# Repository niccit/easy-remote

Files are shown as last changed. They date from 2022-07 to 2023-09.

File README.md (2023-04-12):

# Easy Remote with LED Display

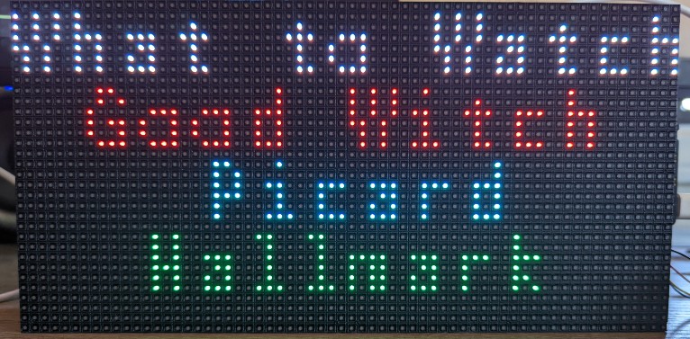
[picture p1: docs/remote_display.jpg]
Picture of LED display


## The Need
As my mom gets older, she is having trouble working the remote for her Roku devices.

I searched for a senior-friendly remote that worked with Roku but was unable to find one that didn't have way too many tiny buttons on it.

## The Solution
Build a 4-button remote with a large display.

Color code the buttons, LED lights on the keyboard, and text on the display.
- Red: Netflix
- Blue: Paramount/Pluto TV
- Green: Hallmark
- White: Power

This project is tailored to her watching habits, however, it can be easily modified.

In addition to the keypad this implementation will:
- Interact with the TV streaming Netflix every hour to avoid the "Are you still watching message"
- Turn primary and secondary TVs on and off automatically

## How it works
The project is coded in <a href="https://circuitpython.org/" target="_blank">CircuitPython</a>

You will notice that there are four launch_service methods, although only three can be used if you leave the fourth button for power. I added the launch_pluto method late and just swapped it out with the launch_paramount method. Hopefully, this shows how flexible you can be with this project.

You will need to create your own secrets file based on the example file included in the project. Documentation for building a secrets file can be found <a href="https://learn.adafruit.com/electronic-history-of-the-day-with-pyportal/code-walkthrough-secrets-py" target="_blank">here.</a>

To better understand how to interact with the Roku devices, please visit the <a href="`https://developer.roku.com/en-ca/docs/developer-program/debugging/external-control-api.md`" target="_blank">Roku Developers : External Control Protocol (ECP) documentation.</a>

Adafruit libraries this project needs:
- adafruit_bitmap_font
- adafruit_bus_device
- adafruit_display_text
- adafruit_esp32spi
- adafruit_io
- adafruit_neokey
- adafruit_matrixportal
- adafruit_requests.mpy

All configurable data is stored in the data file:
- device_hosts : One or more Roku devices available on the network
- service_port : The service port for the Roku device
- shows : The shows the person using this remote likes to watch
- channels :  The Roku channel names
- channel_numbers : The corresponding Roku channel IDs - see the ECP for how to get a channel ID
- frndly_guide_position : Unfortunately, Frndly TV app currently doesn't support the Roku search controls. For now you have to find your channel in the guide and count how many down from the top it is and us it for this value.
- netflix_search_int : Netflix doesn't put you back to the starting position on the search grid, so you have to note how many moves right it is from the last letter in your search to the program you want to select.
- paramount_search_int : Paramount moves where they leave the search cursor, use this value to change how many times to move the cursor in order to select the desired show
- primary_tv_start_time : The time, stored in an array [h, m], you want the primary television to turn on each day
- primary_tv_end_time : The time, stored in an array [h, m], you want the primary television to turn off each day
- secondary_tv_start_time: The time, stored in an array [h, m], you want the secondary television to turn on each day
- secondary_tv_end_time: The time, stored in an array [h, m], you want the secondary television to turn off each day
- update_delay : This is the first of the main while loops. General setup/housekeeping, doesn't need to run often. Set to 1 hour
- interact_delay: This is the second of the main while loops, it interacts with Netflix and handles automatic start/stop of the devices. Set to 20 miutes
- remote_reboot_time: The time, stored in an array [h, m], you want the remote to reboot each day

### Why I chose to use a data file?
I wanted the code to be flexible with as little hard coding as possible. It's much easier to edit the data file then to make changes directly in the code.

## The hardware
All the hardware is from <a href="https://www.adafruit.com" target="_blank">Adafruit.</a>

- <a href="https://www.adafruit.com/product/4812" target="_blank">Adafruit Matrix Portal Starter Kit - ADABOX 016 Essentials</a>
  - You can also get all the parts separately:
    - <a href="https://www.adafruit.com/product/4745" target="_blank">Adafruit Matrix Portal</a>
    - <a href="https://www.adafruit.com/product/2278" target="_blank">64 x 32 RGB Matrix</a>
    - <a href="https://www.adafruit.com/product/4749" target="_blank">LED Diffusion Acrylic</a>
    - <a href="https://www.adafruit.com/product/4813" target="_blank">Adhesive Squares</a>
    - <a href="https://www.adafruit.com/product/1995" target="_blank">5V 2.4A Power Supply</a> + <a href="https://www.adafruit.com/product/4299" target="_blank">USB C adapter</a>
- <a href="https://www.adafruit.com/product/4980" target="_blank">NeoKey 1x4 QT I2C - Four Mechanical Key Switches with NeoPixels - STEMMA QT / Qwiic</a>
    - If you want to include the volume buttons you'll need a second NeoKey keyboard
    - I've modified the OpenSCAD file for the keyboard case to support 2 or 4 keys
- <a href="https://www.adafruit.com/product/4955" target="_blank">Kailh Mechanical Key Switches - Clicky White - 10 pack - Cherry MX White Compatible</a>
- <a href="https://www.adafruit.com/product/4997" target="_blank">DSA Keycaps for MX Compatipe Switches - 10 pack</a>
	 - Colors used: Red, Dark Blue, Neon Green, White
- <a href="https://www.adafruit.com/product/4210" target="_blank">STEMMA QT/Qwiic JST SH 4-pin Cable - 100mm long</a>
	 - You can also build your own
- <a href="https://www.adafruit.com/product/4756" target="_blank">Adafruit LTC4311 `I2C Extender / Active Terminator` - STEMMA QT / Qwiic</a>
      - You need this if you want to run a long STEMMA QT cable - so the remote can sit in front of the remote, not on the side

## 3D printing
The stand is designed in OpenSCAD and the source and STL files are included in the project. For my printer I had to break the stand into two halves. In order to do this there is a mortise/tenon joint to join the halves. If your printer is big enough you can print the whole unit at once. STL files are provided for each half, the entire stand, the keyboard cover, offsets, and screws.

No matter how you print it you will need to print the offsets, screws, and keyboard cover separately.
- If you have M3 screws and offsets you can forego printing those
- if you have M4 screws you can forego printing the screws
- The LED display has M3 threaded holes
- The offsets and keyboard tray use M4 threaded holes
  - I went up to M4 because I found that size printed more reliably

I have not included supports in the STL files. You will need to add supports into your slicer or the print will not come out as intended.

The logo on the back of the stand is my 'tip of the hat' and thank you to Adafruit and the Adafruit community. Feel free to comment out the design or substitute your own.

- Printer - Flashforge Adventurer 4
- Slicing software - FlashPrint

- Filament and Slicing:
   - PLA for the stand, offset, and screws
      - Standard 1.75mm filament
      - Extruder: .4/240c
      - Extruder Temp: 210c
      - Platform Temp: 50
      - Supports:
         - Yes for the tenon joint on the left side
            - Linear
            - Manual
	 - Raft: Yes for the stand
	    - Above Raft Extrusion Ratio : 75%
	    - Space to Model (Z) : 0.18mm
   - PETG for the keyboard cover
      - Color: Transparent
      - Extruder: .4/265c
      - Extruder Temp: 240c
      - Platform Temp: 80c
      - Supports: No
      - Raft: Yes
        - Above Raft Extrusion Ratio : 75%
        - Space to Model (Z) : 0.18mm

Huge thank you to HopefulLlama and rcoyler for sharing their libraries with the OpenSCAD community!

- Joint library provided by HopefulLlama
  - <a href="https://github.com/HopefulLlama/JointSCAD" target="_blank">Github project</a>
  - <a href="https://www.thingiverse.com/groups/openscad/forums/general/topic:14842" target="_blank">Thingiverse</a>
- Threads library provided by rcoyler
  - <a href="https://github.com/rcolyer/threads-scad" target="_blank">Github project</a>

## To-Do

- Switch to a socketpool
   - I'm hoping this helps with overall stability
	- In addition it will allow the user to push a button while backround checks and maintenance tasks are happening

 ## FAQ

 - My remote is up and running, but after about 6-8 hours it stops communicating with the devices. If I look at the REPL it says my active devices are inactive.
   - You are likely running the default firmware on your Matrix Portal M4 board
	- **Solution:** Upgrade the firmware, by following these [instructions](https://learn.adafruit.com/upgrading-esp32-firmware/upgrade-all-in-one-esp32-airlift-firmware).

- The software periodically crashes with a seesaw error, when I reset I get the error message "No pull up found. check your wiring".
  - **FIRST:** Ensure you're using a [STEMMA QT/Qwiic cable](https://www.adafruit.com/product/4399)
  - Posted in the Adafruit forums about this issue. 
  - **Solution** This seems to be specific to this board, so between your Matrix Portal 4 and the Keyboard, put an Adafruit LTC4311 I2C Extender / Active Terminator - STEMMA QT / Qwiic
     - The part is linked above in the hardware section.

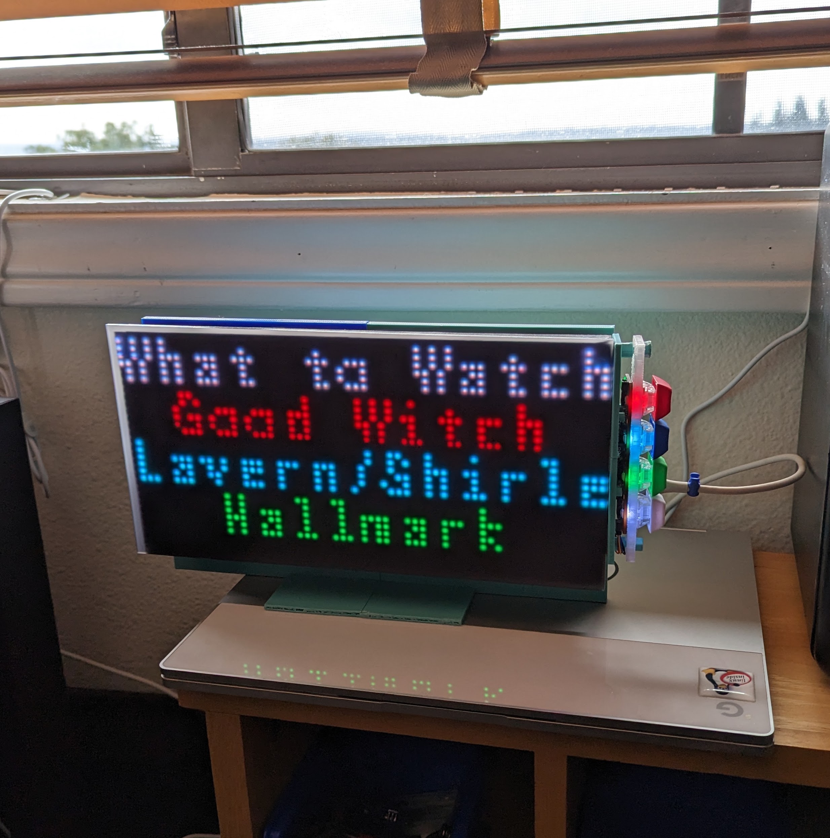
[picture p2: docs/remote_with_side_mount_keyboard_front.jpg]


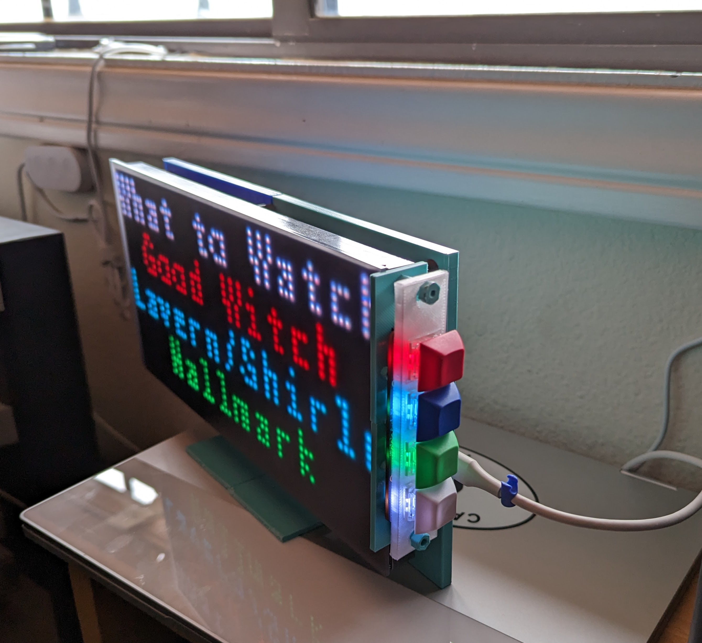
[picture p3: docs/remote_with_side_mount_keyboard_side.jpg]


- Every so often the screen is stuck on "Loading Please Wait"
   - See the To-Do list

- Every so often the remote is unresponsive when pressing a button or it takes a long time to start handling the button request
   - See the To-Do list

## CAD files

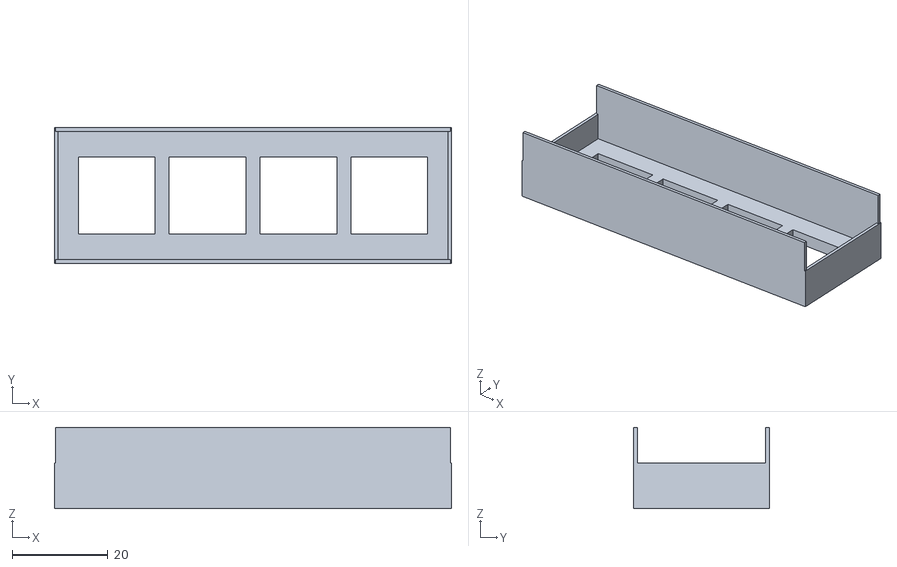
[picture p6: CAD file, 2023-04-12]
STL_files/led_keyboard_cover.stl
82.9 x 28.3 x 17.0

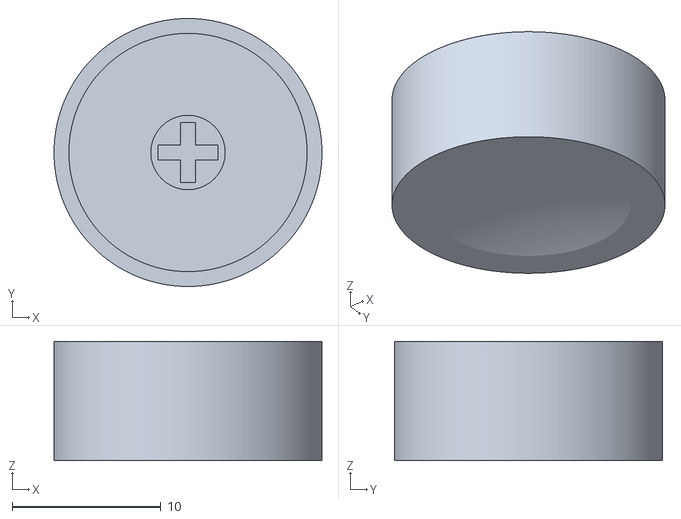
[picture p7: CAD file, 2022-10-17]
STL_files/keycap_round_blank.stl
18.0 x 18.0 x 8.00

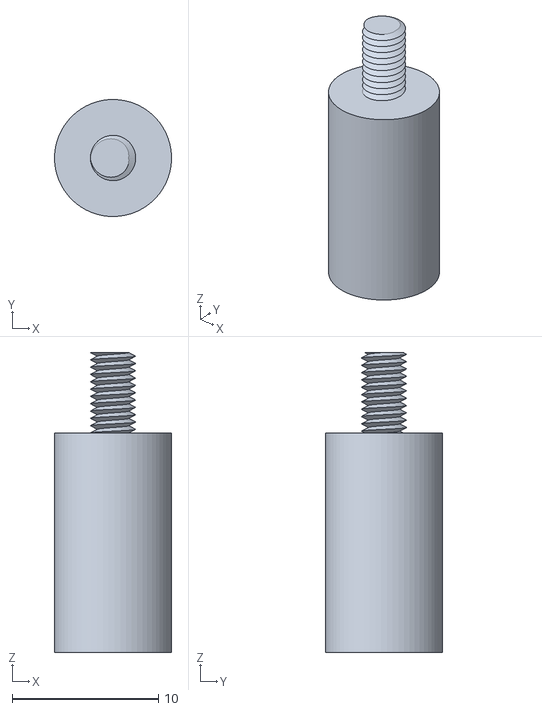
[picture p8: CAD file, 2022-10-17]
STL_files/led_stand_offset.stl
8.00 x 8.00 x 20.5

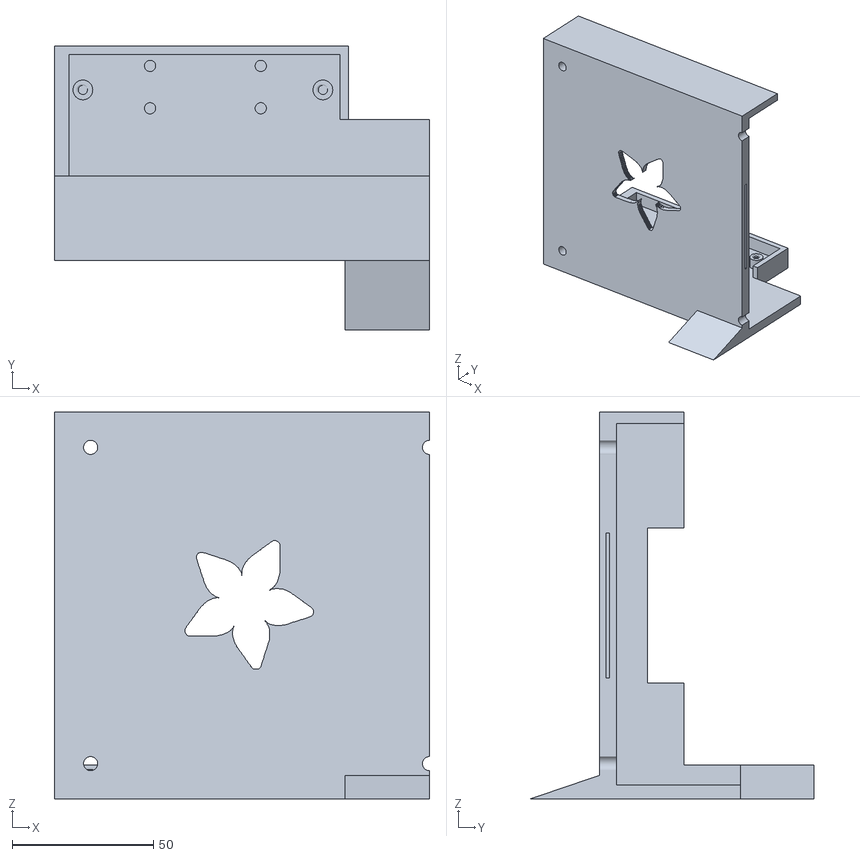
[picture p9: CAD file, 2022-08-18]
STL_files/led_stand_backplate_right.stl
132.8 x 100.5 x 137.0

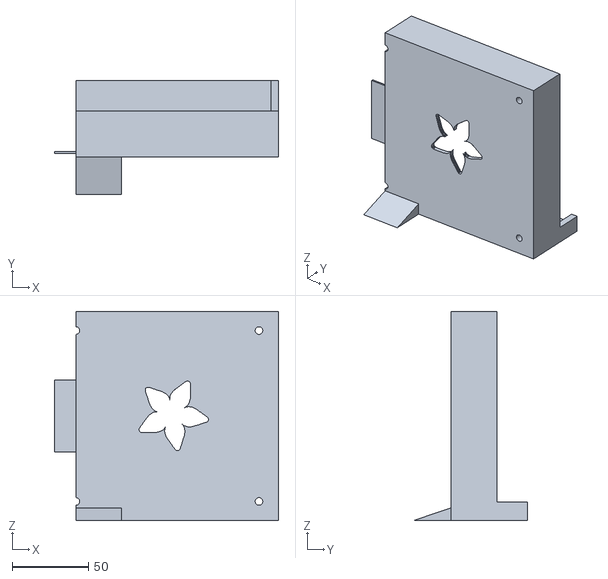
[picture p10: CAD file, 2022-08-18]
STL_files/led_stand_backplate_left.stl
146.8 x 74.5 x 137.0

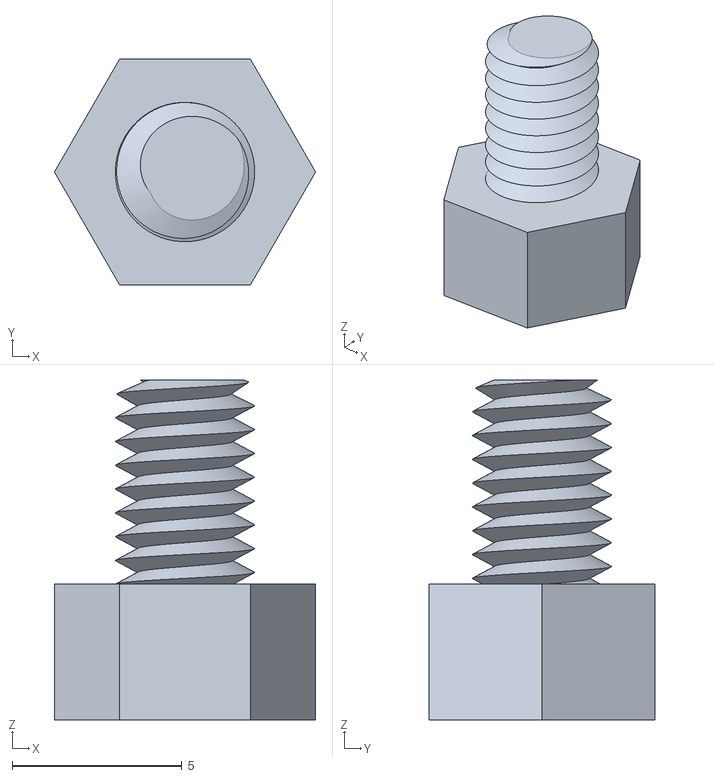
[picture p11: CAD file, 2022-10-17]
STL_files/kb_bolt.stl
7.68 x 6.65 x 10.0

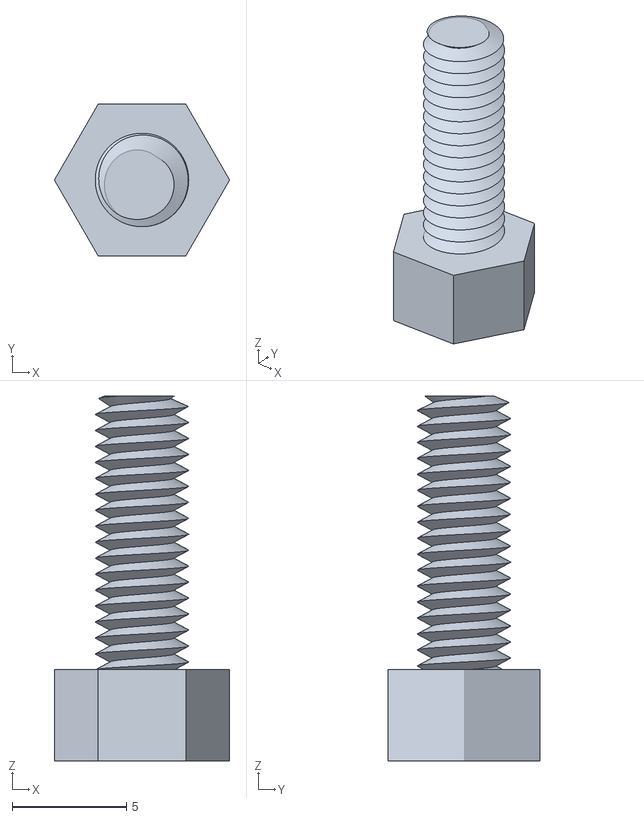
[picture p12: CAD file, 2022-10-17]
STL_files/led_bolt.stl
7.68 x 6.65 x 16.0

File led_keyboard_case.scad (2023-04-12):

// SPDX-License-Identifier: MIT
$fa = 1;
$fs = 0.4;

// keyboard tray
kb_length = 76.2;
kb_width = 21.59;
kb_height = 4;

front_length = kb_length;
front_width = 17;
front_height = 0.75;

mounting_hole_diam = 2.45;
mounting_hole_height = 4;
mounting_hole_distance = 2.51;

// ### Begin Modules ###

module base_cube() {
    difference() {
        cube([kb_length + 10, kb_width + 10, kb_height], center=true);
        translate([0, 0, kb_height])
            cube([kb_length + 8, kb_width + 8, kb_height + 1]);
    }
}

// For fitting top and bottom together
module base_hollow_outline() {
    difference() {
        cube([kb_length + 7, kb_width + 7, kb_height], center=true);
        cube([kb_length + 5, kb_width + 5, kb_height + 1], center=true);
    }
}

module base_with_snapfit() {
    difference() {
        base_cube();
        translate([0, 0, kb_height - 1.5])
            base_hollow_outline();
    }
}

module complete_base() {
    difference() {
        base_with_snapfit();
        translate([-kb_length/2 + 19.05, kb_width/2 - mounting_hole_distance, 0])
            cylinder(d=mounting_hole_diam, h=mounting_hole_height, center=true);
        translate([kb_length/2 - 19.05, kb_width/2 - mounting_hole_distance, 0])
            cylinder(d=mounting_hole_diam, h=mounting_hole_height, center=true);
        translate([-kb_length/2 + 19.05, -kb_width/2 + mounting_hole_distance, 0])
            cylinder(d=mounting_hole_diam, h=mounting_hole_height, center=true);
        translate([kb_length/2 - 19.05, -kb_width/2 + mounting_hole_distance, 0])
            cylinder(d=mounting_hole_diam, h=mounting_hole_height, center=true);
    }
}

module keyboard_cover(num, space) {
  difference() {
    cube([kb_length + 6.25, kb_width + 6, kb_height - 1], center=true);
		for (i = [0 : num - 1])
            if (num == 4) {
                translate([-kb_length / 2 + 9.6 + space*i, 0, 0])
                    children(0);
            }
            else {
                translate([-kb_length / 2 + 29 + space*i, 0, 0])
                    children(0);
            }
	}
    // front
    rotate([90,0,0])
    translate([0, -front_width / 2 + 1.5, kb_width / 2 + 3 - 0.001])
        cube([front_length + 6.25, front_width, front_height], center = true);
    // back
    rotate([90,0,0])
    translate([0, -front_width / 2 + 1.5, -kb_width / 2 - 3 - 0.001])
        cube([front_length + 6.25, front_width, front_height], center = true);
    // left side
    rotate([90, 0, 90])
    if (num == 4) {
        translate([0, -front_width / 2 + 5.25, kb_length / 2 + 3 - 0.001])
        cube([kb_width + 6.75, front_width - 7.5, front_height], center = true);
    }
    else {
        translate([0, -front_width / 2 + 1.5, kb_length / 2 + 3 - 0.001])
        cube([kb_width + 6.75, front_width, front_height], center = true);
    }
    // right side
   rotate([90, 0, 90])
   translate([0, -front_width / 2 + 5.25, -kb_length / 2 - 3 - 0.001])
        cube([kb_width + 6.75, front_width - 7.5, front_height], center = true);
}


module key_holes(){
  cube([16, 16, kb_height], center=true);
}

// ### End Modules ###

// Construction of the parts

show_base = 0;
show_top = 0;
show_all = 1;
do_rotate = 0;
keys = 4;


if (show_base == 1) {
    if (do_rotate == 1) {
        rotate([180, 0, 0])
            complete_base();
    }
    else {
        complete_base();
    }
}

if (show_top == 1) {
    if (do_rotate == 1) {
        rotate([180, 0, 0])
            keyboard_cover(keys, 19) key_holes();
    }
    else {
        keyboard_cover(keys, 19) key_holes();
    }
}

if (show_all == 1) {
    complete_base();
    rotate([180, 0, 0])
    translate([kb_length + 20, 0, 0])
        keyboard_cover(4, 19) key_holes();
}

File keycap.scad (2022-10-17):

// SPDX-License-Identifier: MIT
//
// A round keycap for Cherry MX keyboard
// Can be blank or have a raised letter added
//

$fa = 1;
$fs = 0.4;

difference() {
	// outer cylinder
	outer_cylinder();
	// inner cylinder
	translate([0, 0, 1])
		cylinder(r=8, h=7, center=true);
}

translate([0, 0, 0.25 - 0.001])
	key_lock();

//
// Show a letter on your key
// Use 0 for a blank key
//
translate([0.5, 0, 0])
	show_text(0);

//
// Modules
//

module outer_cylinder() {
	difference() {
		cylinder(r=9, h=8, center=true);
			rotate([0,180,0])
			translate([0, 0, 26])
				sphere(r=23);
	}
}

module key_lock () {
	difference() {
		cylinder(r=2.5, h=6, center=true);
		translate([0,0,1])
			cube([1, 4, 5], center=true);
		translate([0,0,1])
			cube([4, 1, 5], center=true);
	}
}

module show_text (num) {
	rotate([180,0,0])
	if (num==1)
		translate([-4.5, -3.5, 3])
			linear_extrude(height = 1)
				text("N", font = "Liberation Sans:style=Bold", size= 8);
	else if (num==2)
		translate([-4, -3.5, 3])
			linear_extrude(height = 1)
				text("P", font = "Liberation Sans:style=Bold", size=8);
	else if (num==3)
		translate([-4.5, -3.5, 3])
			linear_extrude(height = 1)
				text("H", font = "Liberation Sans:style=Bold", size=8);
	else if (num==4)
		rotate([0, 0, 180])
		translate([-5, -2.5, 3])
			linear_extrude(height = 1)
				text("Off", font = "Liberation Sans:style=Bold", size=5);
}

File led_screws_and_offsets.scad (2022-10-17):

// SPDX-License-Identifier: MIT
//
// Offsets for mounting display to stand and
// screws for securing display to offsets and keyboard cover
//

use <lib/threads.scad>

$fa = 1;
$fs = 0.4;

// Bolts & Clearance Holes
bolt_size = 4;
offset_bolt = 3;
offset_bolt_height = 6;
kb_bolt_height = 6;
base_bolt_height = 12;
base_screwHole_height = 9;

// Offsets for LED / back of stand
//
offset_with_bolt();

// Bolt for securing LED to back of stand
//
translate([0, 15, -10])
	MetricBolt(bolt_size, base_bolt_height);

// Bolt for securing keyboard cover
//
translate([0, 30, -10])
	MetricBolt(bolt_size, kb_bolt_height);





module offset_base() {
	difference() {
    cylinder(r=4, h=15, center=true);
			ScrewHole(outer_diam=bolt_size, height=base_screwHole_height);
	}
}

module offset_with_bolt() {
	translate([0, 0, 5 - 0.001])
	 ScrewThread(outer_diam=offset_bolt, height=offset_bolt_height);
	rotate([0,180,0])
	translate([0,0,2 - 0.001])
	 offset_base();
}

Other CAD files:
STL_files/keycap_round_hallmark.stl
STL_files/keycap_round_netflix.stl
STL_files/keycap_round_paramount.stl
STL_files/keycap_round_power.stl
led_stand.scad

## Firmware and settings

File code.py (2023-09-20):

# SPDX-License-Identifier: MIT
# This is a very simple remote, designed for individuals with difficulty navigating
# all the different streaming applications
# It was designed to help a senior have less frustration while trying to watch television
import ssl
import time
import board
import displayio
import re
import socketpool
import wifi
import adafruit_requests
import adafruit_ntp
import adafruit_logging as logger
from adafruit_neokey.neokey1x4 import NeoKey1x4

# Get WiFi information from secrets.py file
try:
    from secrets import secrets
except ImportError:
    print("WiFi secrets are kept in secrets.py, please add them there")
    raise

# Get data needed to launch shows and interact with devices
try:
    from data import data
except ImportError:
    print("Cannot import data file")
    raise

# Get what we need from the data file
hosts = data["device_hosts"]
port = data["service_port"]
current_shows = data["shows"]
current_channels = data["channels"]
channel_ids = data["channel_numbers"]
pluto_shows = data["pluto_shows_array"]
roku_shows = data["roku_shows_array"]
paramount_shows = data["paramount_shows_array"]
netflix_search_int = data["netflix_search_array"]
primary_tv_start_time = data["primary_tv_start_time"]
primary_tv_end_time = data["primary_tv_end_time"]
primary_tv_channel = data["primary_tv_channel"]
secondary_tv_start_time = data["secondary_tv_start_time"]
secondary_tv_end_time = data["secondary_tv_end_time"]
secondary_tv_channel = data["secondary_tv_channel"]
secondary_device = data["secondary_device_active"]
update_delay = data["update_delay"]
interact_delay = data["interact_delay"]
key_input_delay = data["key_input_delay"]
live_check = data["live_check"]
tz_offset = data["tz_offset"]
log_level = data["log_level"]

# --- Setup  ---

# Network Variables
SSID = secrets["ssid"]
WIFI_PASS = secrets["password"]

# Device Interaction Variables
INPUT_WAIT_TIME = key_input_delay
CHECK_STRING = live_check
TZ_OFFSET = float(tz_offset)
if secondary_device != 0:  # There is a second TV in the house
    SECOND_TV = True
else:  # There is only one TV
    SECOND_TV = False
CHOICE = 0
RUNNING_APP = 0
RUNNING_SHOW = None
LAST_CHECK = None
INTERACT_CHECK = None
PRIMARY_ACTIVE_APP = None
SECONDARY_ACTIVE_APP = None
PRIMARY_CHANNEL_NAME = None
SECONDARY_CHANNEL_NAME = None
PRIMARY_SHOW_NAME = None
SECONDARY_SHOW_NAME = None

# Logging
LOGGER = logger.getLogger('console')
if log_level is "debug":
    LOGGER.setLevel(logger.DEBUG)
elif log_level is "info":
    LOGGER.setLevel(logger.INFO)
elif log_level is "warning":
    LOGGER.setLevel(logger.WARNING)
elif log_level is "error":
    LOGGER.setLevel(logger.ERROR)
elif log_level is "critical":
    LOGGER.setLevel(logger.CRITICAL)
else:
    print("setting log level to critical")
    LOGGER.setLevel(logger.CRITICAL)

LOGGER.info("log level is " + log_level)

# URLs
URL_1 = ("http://" + hosts[0] + ":" + port + "/")
URL_2 = ("http://" + hosts[1] + ":" + port + "/")

# Host IPs, for ping check
HOST_1_IP = hosts[0]
HOST_2_IP = hosts[1]

# Build array of channel ID ints
CHANNEL_ID_INTS = []
for i in range(len(channel_ids)):
    CHANNEL_ID_INTS.append(int(channel_ids[i]))

# --- Network Setup --- #

# Socketpool and requests for talking to devices
pool = socketpool.SocketPool(wifi.radio)
requests = adafruit_requests.Session(pool, ssl.create_default_context())

# NTP
ntp = adafruit_ntp.NTP(pool, tz_offset=TZ_OFFSET)

# --- Neokey Setup --- #

color = displayio.Palette(7)
color[0] = 0XFF0000  # red = Show 1
color[1] = 0x008000  # green = Show 3

i2c_bus = board.STEMMA_I2C()
neokey = NeoKey1x4(i2c_bus, addr=0x30)

# Set colors for the keyboard
neokey.pixels[0] = color[1]
neokey.pixels[3] = color[0]


# --- Roku API Calls --- #
home = "keypress/home"  # Home
right = "keypress/right"  # Right
left = "keypress/left"  # Left
up = "keypress/up"  # Up
down = "keypress/down"  # Down
back = "keypress/back"  # Back
select = "keypress/select"  # Select
vol_up = "keypress/volumeup"  # Volume Up
vol_down = "keypress/volumedown"  # Volume Down
pwr_on = "keypress/poweron"  # Power On
pwr_off = "keypress/poweroff"  # Power Off
launch = "launch/"  # Launch a Channel
active_app = "query/active-app"  # Query Active Application
query_media = "query/media-player"  # Query Device State


# --- Helper methods not related to Roku devices --- #

# Get current time from NTP and return it
def get_time():
    cur_time = None

    while cur_time is None:
        try:
            cur_time = ntp.datetime
        except RuntimeError as e:
            LOGGER.error("get_time: An error occurred, retrying ... " + str(e))
            continue

    return cur_time


# Convert a show name to an array for searching
def get_show_search_array(show_to_watch):
    show_to_split = show_to_watch.split()
    show_to_split_length = len(show_to_split)
    show_array = []
    counter = 0
    for word in show_to_split:
        counter += 1
        if counter < show_to_split_length:
            show_array += list(word)
            show_array += " "
        else:
            show_array += list(word)
    return show_array


# --- Helper methods to assist in channel/show launching --- #

# Set global variables needed to interact with the devices
def set_channel_and_show(url, show_to_watch):
    global PRIMARY_CHANNEL_NAME, SECONDARY_CHANNEL_NAME, PRIMARY_SHOW_NAME, SECONDARY_SHOW_NAME, \
        PRIMARY_ACTIVE_APP, SECONDARY_ACTIVE_APP

    show_configured = False

    while show_configured is False:
        for show in range(len(current_shows)):
            if show_to_watch is current_shows[show]:
                channel_to_watch = current_channels[show]
                app_to_watch = channel_ids[show]
                if url is URL_1:
                    PRIMARY_CHANNEL_NAME = channel_to_watch
                    PRIMARY_SHOW_NAME = show_to_watch
                    PRIMARY_ACTIVE_APP = int(app_to_watch)
                else:
                    SECONDARY_CHANNEL_NAME = channel_to_watch
                    SECONDARY_SHOW_NAME = show_to_watch
                    SECONDARY_ACTIVE_APP = int(app_to_watch)
                show_configured = True


# Use in-channel search to locate show to watch
# Using search as a more reliable way to find what to watch
def search_program(url, show_to_watch):
    if url:
        device_url = url
    else:
        device_url = URL_1

    search_show = get_show_search_array(show_to_watch)
    time.sleep(1)

    for letter in search_show:
        command = ("keypress/Lit_" + letter)
        send_request(device_url, command)
        time.sleep(0.5)


# Query the devices to determine if they are online
def get_device_state(url):
    device_state = "inactive"

    if url:
        device_url = url
    else:
        device_url = URL_1

    LOGGER.debug("get_device_state: querying " + str(device_url) + " for status")
    if send_request(device_url, query_media) is not None:
        device_state = "active"

    return device_state


# Get the active app ID
def get_active_app(url):
    active_channel = 0

    if url:
        device_url = url
    else:
        device_url = URL_1

    if device_url is URL_1:
        app_state = primary_device_state
        app_id_to_check = PRIMARY_ACTIVE_APP
    else:
        app_state = secondary_device_state
        app_id_to_check = SECONDARY_ACTIVE_APP

    if app_state is "active" and app_id_to_check is None:
        LOGGER.debug("get_active_app: Attempting to get active channel for device " + str(device_url))
        channel_text = send_request(device_url, active_app)
        if channel_text is not None:
            regex = re.compile("[\r\n]")
            parsed_response = regex.split(channel_text)
            regex = re.compile("[\"]")
            tmp_channel = (regex.split(parsed_response[2]))
            active_channel = tmp_channel[1]
        else:
            LOGGER.critical("get_active_app: failed to get response from device for active channel")
    else:
        print("already have active app for URL")
        active_channel = app_id_to_check

    LOGGER.debug("active app is now set to " + str(active_channel))

    return active_channel


# Determine which item we want in a channel's watch list
# This only works as long as the show stays in the watch list after viewing it
#    and the app doesn't shift the position of the items in the watch list based
#    on what was watched most recently
def get_addtl_show_info(show_to_watch, channel):
    position = 0
    search_array = []
    if channel is "Pluto":
        search_array = pluto_shows
    if channel is "Roku":
        search_array = roku_shows
    if channel is "Paramount":
        search_array = paramount_shows
    if channel is "Netflix":
        search_array = netflix_search_int

    for show in range(len(search_array)):
        if show_to_watch in search_array[show]:
            show = search_array[show]
            position = show[1]
    return position


# Send command to appropriate Roku device
def send_request(url, command):
    result = None

    try:
        if "active-app" in command:
            LOGGER.debug("querying for active app")
            response = requests.get(url + command)
            result = response.text
            response.close()
        elif "media-player" in command:
            LOGGER.debug("querying media player")
            response = requests.get(url + command)
            result = response.text
            response.close()
        else:
            response = requests.post(url + command)
            result = "true"
            response.close()
    except Exception as e:
        LOGGER.error("send_request: Caught generic exception " + str(e) + " for command " + str(command))

    return result


# Exit current running app and power down the Roku TV or put the Roku device into sleep mode
def power_off(url):
    LOGGER.info("request to power off")
    if url:
        device_url = url
    else:
        device_url = URL_1

    if device_url is URL_1:
        app = PRIMARY_ACTIVE_APP
    else:
        app = SECONDARY_ACTIVE_APP

    # Check to see if we need to properly exit or if we can just return to home screen
    if app == 12:
        exit_netflix(device_url)
        time.sleep(1)
    elif app == 74519:
        exit_pluto(device_url)
        time.sleep(1)
    else:
        send_request(device_url, home)
        time.sleep(1)

    send_request(device_url, pwr_off)


# Return to home screen, needed when we don't know the current state
def return_home(url):
    LOGGER.debug("eject Buckaroo!")
    if url:
        device_url = url
    else:
        device_url = URL_1

    if device_url is URL_1:
        app = PRIMARY_ACTIVE_APP
    else:
        app = SECONDARY_ACTIVE_APP

    # Check to see if we need to properly exit or if we can just return to home screen
    if app == 12:
        exit_netflix(device_url)
        time.sleep(1)
    elif app == 74519:
        exit_pluto(device_url)
        time.sleep(1)
    else:
        send_request(device_url, home)
        time.sleep(1)

# --- Helper methods to launch, exit, and search within open channels --- #

# --- Netflix --- #


def launch_netflix(url, show_to_watch, app):
    if url:
        device_url = url
    else:
        device_url = URL_1

    if device_url is URL_1:
        channel = PRIMARY_CHANNEL_NAME
        show = PRIMARY_SHOW_NAME
    else:
        channel = SECONDARY_CHANNEL_NAME
        show = SECONDARY_SHOW_NAME

    # Check to see if we need to properly exit or if we can just return to home screen
    if RUNNING_APP == 74519:
        exit_pluto(device_url)
        time.sleep(1)
    elif RUNNING_APP != int(app):
        send_request(device_url, home)
        time.sleep(1)

    channel_call = (launch + str(app))

    if RUNNING_APP == app:
        LOGGER.debug(str(app) + " is already running")
        current_show = RUNNING_SHOW
        show_letters_array = get_show_search_array(current_show)
        LOGGER.debug("need to remove " + str(len(show_letters_array)) + " before new search")
        for nav in range(2):
            send_request(device_url, back)
            time.sleep(1)
        send_request(device_url, left)
        time.sleep(1)
        for letter in range(len(show_letters_array)):
            send_request(device_url, select)
            time.sleep(0.5)
        send_request(device_url, left)
        time.sleep(1)
    else:
        LOGGER.debug(str(app) + " is not running, will launch channel")
        send_request(device_url, channel_call)  # launch Netflix
        time.sleep(15)
        # This is only for a multi-profile account
        # Comment out if only one profile
        send_request(device_url, select)  # select the active profile
        time.sleep(2)
        send_request(device_url, left)  # open the left nav menu
        time.sleep(1)
        send_request(device_url, up)  # navigate to Search
        time.sleep(1)
        send_request(device_url, select)
        time.sleep(1)

    search_program(url, show_to_watch)
    time.sleep(1)
    search_int = get_addtl_show_info(show_to_watch, channel)
    for nav in range(search_int):
        send_request(device_url, right)
        time.sleep(1)
    send_request(device_url, select)
    time.sleep(1)
    send_request(device_url, select)  # Start the show, don't wait for autostart

    LOGGER.info("launched " + str(show_to_watch) + " on " + str(channel) + " on device " + str(device_url))


# Exit Netflix properly to ensure we return to a known location
def exit_netflix(url):
    if url:
        device_url = url
    else:
        device_url = URL_1

    return_range = 4

    LOGGER.info("exiting Netflix")
    for x in range(return_range):  # Get back to left nav
        send_request(device_url, back)
        time.sleep(1)
    send_request(device_url, down)  # Return to home screen
    time.sleep(1)
    send_request(device_url, select)  # Return to home screen
    time.sleep(0.5)
    send_request(device_url, left)  # Return to left nav
    time.sleep(1)
    # Only needed if using a multi-profile account
    for nav in range(4):  # Move up to the profile
        send_request(device_url, up)
        time.sleep(1)
    send_request(device_url, select)  # Select it to land on profiles page
    time.sleep(1)
    send_request(device_url, home)


# Netflix likes to save your data by asking "are you still watching"
# Since we don't worry about that on these devices, interacting
# with the TV periodically will prevent them from popping up
def interact_with_netflix(url):
    if url:
        device_url = url
    else:
        device_url = URL_1

    netflix_show_status = send_request(device_url, query_media)
    if "pause" in netflix_show_status or "stop" in netflix_show_status:
        print("")
    else:
        LOGGER.debug("interact_with_tv: Interacting with TV to avoid Netflix prompt")
        send_request(device_url, up)
        time.sleep(1)

# --- Pluto --- #


def launch_pluto(url, show_to_watch, app):
    if url:
        device_url = url
    else:
        device_url = URL_1

    # Check to see if Netflix is active, if so exit app before starting new show
    if RUNNING_APP == 12:
        exit_netflix(device_url)
        time.sleep(1)
    elif RUNNING_APP != int(app):
        send_request(device_url, home)

    if device_url is URL_1:
        channel = PRIMARY_CHANNEL_NAME
        show = PRIMARY_SHOW_NAME
    else:
        channel = SECONDARY_CHANNEL_NAME
        show = SECONDARY_SHOW_NAME

    watch_list_pos = get_addtl_show_info(show_to_watch, channel)

    # Don't relaunch the app if already watching, just move back to root of On Demand Menu
    # Otherwise launch the app and navigate to On Demand Menu
    if RUNNING_APP == int(app):
        LOGGER.debug(str(app) + " already running")
        for nav in range(3):
            send_request(device_url, back)
            time.sleep(1)
    else:
        LOGGER.debug(str(app) + " not running, launch app")
        channel_call = (launch + str(app))
        wait_for_start = True
        send_request(device_url, channel_call)  # launch Pluto TV

        while wait_for_start is True:
            # Check to see if currently streaming live tv
            if CHECK_STRING in send_request(url, query_media):
                wait_for_start = False
                LOGGER.debug("station loaded, ready to proceed")
            else:
                LOGGER.debug("waiting for channel to launch")
                time.sleep(4)
        LOGGER.debug("start launch procedure")
        for nav in range(2):  # Open left nav, hit left twice in case the Guide button has timed out
            send_request(device_url, left)
            time.sleep(1)
        for nav in range(2):
            send_request(device_url, down)  # Navigate to On Demand
            time.sleep(1)
        send_request(device_url, select)  # Select On Demand
        time.sleep(1)

    for nav in range(2):
        send_request(device_url, down)  # Navigate to Watch List
        time.sleep(2)
    for nav in range(watch_list_pos):
        send_request(device_url, right)  # Move to the chosen show in the watch list
        time.sleep(1)
    send_request(device_url, select)
    time.sleep(1)
    send_request(device_url, select)
    time.sleep(5)
    confirm_pluto_show_loaded(device_url, show_to_watch)

    LOGGER.info("launched " + str(show_to_watch) + " on " + str(channel) + " on device " + str(device_url))


# Check that chosen show actually loaded the program we want
def confirm_pluto_show_loaded(url, show_to_watch):
    show_launched = False

    if url:
        device_url = url
    else:
        device_url = URL_1

    LOGGER.debug("confirming chosen PlutoTV show has launched")
    while show_launched is False:

        # Check to see if currently streaming live tv
        if CHECK_STRING in send_request(url, query_media):
            LOGGER.warning("Didn't launch chosen show, trying again")
            launch_channel(device_url, 74519, show_to_watch)  # attempt to relaunch show
        else:
            LOGGER.info("Chosen show successfully launched")
            show_launched = True

        time.sleep(2)


# Exit Pluto properly so that we're at a known good starting spot upon return
def exit_pluto(url):
    if url:
        device_url = url
    else:
        device_url = URL_1

    # Check to see if currently streaming live tv
    if CHECK_STRING in send_request(url, query_media):
        return_range = 4
    else:
        return_range = 5

    LOGGER.info("exiting Pluto")
    for x in range(return_range):  # Exit App
        send_request(device_url, back)
        time.sleep(2)
    send_request(device_url, down)  # Navigate to Exit App in selection
    time.sleep(1)
    send_request(device_url, select)  # Exit app, return to home screen

# --- YouTube TV --- #


def launch_youtubetv(url, show_to_watch, app):
    if url:
        device_url = url
    else:
        device_url = URL_1

    # Check to see if we need to properly exit or if we can just return to home screen
    if RUNNING_APP == 12:
        exit_netflix(device_url)
        time.sleep(1)
    elif RUNNING_APP == 74519:
        exit_pluto(device_url)
        time.sleep(1)
    elif RUNNING_APP != int(app):
        send_request(device_url, home)
        time.sleep(1)

    if device_url is URL_1:
        channel = PRIMARY_CHANNEL_NAME
        show = PRIMARY_SHOW_NAME
    else:
        channel = SECONDARY_CHANNEL_NAME
        show = SECONDARY_SHOW_NAME

    channel_call = (launch + str(app))

    if RUNNING_APP is app and RUNNING_SHOW is not "Steelers":
        youtube_return_to_search(device_url)
    else:
        if RUNNING_SHOW is "Steelers":
            return_home(device_url)
        time.sleep(2)
        send_request(device_url, channel_call)  # launch YouTube TV
        time.sleep(15)
        for nav in range(3):
            send_request(device_url, right)  # Navigate to search
            time.sleep(3)
        send_request(device_url, down)  # Enter search
        time.sleep(1)

    search_program(device_url, show_to_watch)  # Search for channel
    time.sleep(1)
    for nav in range(2):
        send_request(device_url, right)  # Navigate to searched channel
        time.sleep(2)
    send_request(device_url, select)
    time.sleep(1)
    if show_to_watch is "Steelers":
        for nav in range(2):
            send_request(device_url, select)
            time.sleep(1)
    else:
        send_request(device_url, down)
        time.sleep(1)
        for a in range(2):
            send_request(device_url, select)
            time.sleep(1)
        time.sleep(1)

    LOGGER.info("launched " + str(show_to_watch) + " on " + str(channel) + " on device " +  str(device_url))


# Return to search menu and clear prior search for YouTube
def youtube_return_to_search(url):
    nav_range = 4

    for nav in range(nav_range):
        send_request(url, back)
        time.sleep(0.5)
    send_request(url, right)
    time.sleep(1)
    for nav in range(6):
        send_request(url, down)
        time.sleep(0.5)
    send_request(url, select)
    time.sleep(1)
    for nav in range(6):
        send_request(url, up)
        time.sleep(0.5)
    send_request(url, left)
    time.sleep(1)

# --- Roku --- #
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

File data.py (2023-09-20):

data = {
    'device_hosts': ['primary.device.ip.address', 'secondary.device.ip.address'],
    'service_port': '8060',  # The default port for Roku devices
    'shows': ['Good Witch', 'Hallmark', 'Lavern/Shrily', 'TV Land', 'IFC', 'ABC', 'Steelers'],
    'channels': ['Netflix', 'YouTube TV', 'Pluto', 'YouTube TV', 'YouTube TV', 'YouTube TV', 'YouTube TV'],
    'channel_numbers': ['12', '195316', '31440', '196316', '196316', '196316', '196316'],
    'frndly_guide_position': 4,
    'netflix_search_int': 5,
    'paramount_search_int': 6,
    'primary_tv_start_time': [6, 29],
    'primary_tv_end_time': [21, 00],
    'primary_tv_channel': "YouTube TV",  # Which show should we launch each morning on the primary TV
    'secondary_tv_start_time': [19, 29],
    'secondary_tv_end_time': [22, 00],
    'secondary_tv_channel': "YouTube TV",  # Which show should we launch each evening on the secondary TV
    'update_delay': 3600,  # Each hour perform general housekeeping
    'interact_delay': 1200,  # Every 20 minutes perform time specific tasks
    'key_input_delay': 5
}

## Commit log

2022-07-26 openSCAD stand file and STL file for offset posts
    [lcd_stand.scad, lcd_stand_offsets.stl]
2022-07-27 modularized components and entire unit
    [lcd_stand.scad]
2022-08-02 more code clean up and work on the stand
    [lcd_stand.scad, lcd_stand_backplate_left.stl, lcd_stand_backplate_right.stl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]
2022-08-02 removing files that have been moved to subdirectories
    [lcd_stand_offsets.stl]
2022-08-02 added MIT license to project
    [lcd_stand.scad]
2022-08-15 renamed STL and SCAD files for stand and updated README
    [cmx-keycap.stl, lcd_stand.scad, lcd_stand_backplate_left.stl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]
2022-08-18 updated README with 3D printing information, modified code to get channel IDs from data file, more final work on the OpenSCAD model for the stand
    [led_stand.scad, led_stand_backplate_left.stl, led_stand_backplate_right.stl]
2022-10-17 Added new logo images for stand Updated STL files, removed unnecessary exports Reworked code to: Switch to default display message 5 seconds after show is playing Moved TV start times, update delay, 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
    [cmx-keycap.stl, kb_bolt.stl, led_bolt.stl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]
2022-10-17 Broke original OpenSCAD file into several for ease of use. Adding new .scad files Uploading STL files for keycaps
    [keycap.scad, keycap_round_blank.stl, keycap_round_hallmark.stl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]
2022-11-14 code.py: added try/catch blocks to better handle exceptions with the socket and different processes. led_keyboard_cover.scad: removed sides and front led_keyboard_cover.stl: updated to reflect change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
    [led_keyboard_cover.scad, led_keyboard_cover.stl]
2022-11-14 added try/catch blocks to better handle socket and network errors. added a busy flag so two methods shouldn't collide
2022-11-17 added a test aid; which is my best effort at exercising the i2c bus with commands. let the check for socket availability to run indefinitely, just in case 4 iterations isn't enough added small sleep 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
    [code.py]
2022-11-18 reworked all methods to handle the socket calls since it appears every call will need possibly multiple attempts to be successful. Added a single method send_request to handle the calls
    [code.py]
2022-12-09 Moved busy state to send_request function to avoid confusion (#3)
    removed all other busy state references
    added a check to see if the device needs powering on - for TVs
    updated exit_netflix to handle when netflix is in a pause or stop state
    [code.py]
2022-12-12 updated README with pictures of the side-mounted keyboard, using 50mm cable (#4)
2022-12-17 Troubleshoot behavior (#5)
    * fixed typo in auto start command and upped wait time to allow Pluto to fully start when the app is cold
    * removed two unnecessary print statements
    [code.py]
2023-04-12 Stability improvements (#8)
    * changed sleep in routines from 0.5 to 1 second
    close socket after each call
    changed wait for netflix to load to 15 seconds
    changed launch_pluto to use my list rather than continue watching
    * Added back in while loop for general exceptions on socket calls and included a socket close
    Correct bug for querying secondary device for active app
    Set special loading screen when launching upstairs TV
    Added in handling for automatic app to launch to grab from data file
    * corrected looping not happening in send_request method
    corrected if blocks for automatically starting tv shows
    * Corrected poor handling of launching Pluto TV.
    Beginning work on better han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
    [led_keyboard_case.scad, led_keyboard_cover.scad, led_keyboard_cover.stl]
2023-09-20 New board, QT PY ESP32 Pico. Single button operation, adding proper logging, added ability to support more shows since display is no longer needed, if choose show on active channel, no longer exit ap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
    [code.py, data.py]
